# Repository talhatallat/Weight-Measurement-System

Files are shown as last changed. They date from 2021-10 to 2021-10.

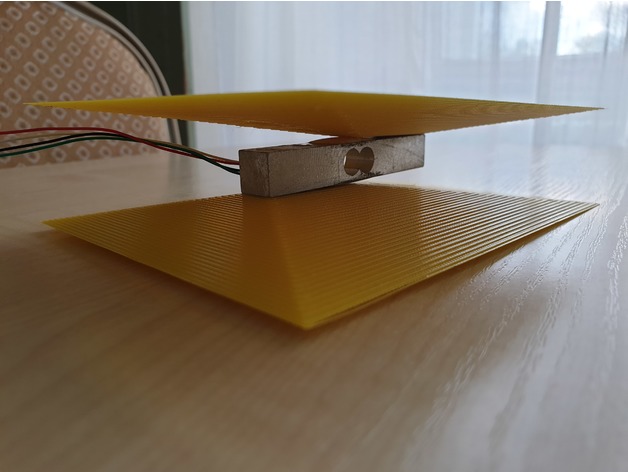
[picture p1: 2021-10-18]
Weight messurment device images/printed.jpg

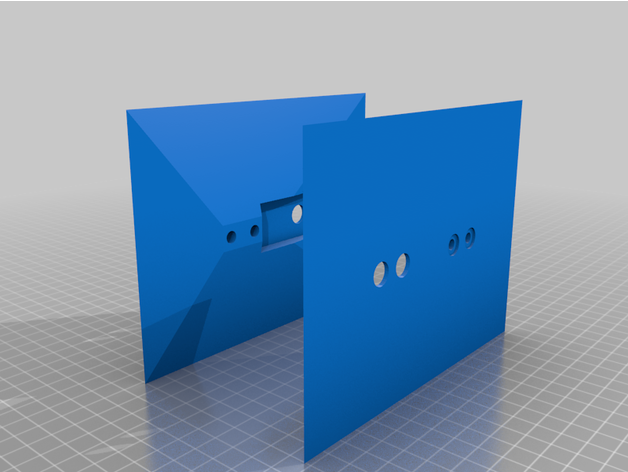
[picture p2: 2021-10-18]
Weight messurment device images/Load-cell_20kg-v3.png

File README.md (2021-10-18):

# Weight Measurement System Using LoadCell <a href="https://dt021a-3.wixsite.com/website/about/" target= "_blank" >View Project</a> 

This project uses Arduino Nano which was programmed to measure the weight accurately when the load is applied to the load cell.

## Load Cell 

A load cell measures the weight using strain gauges. The difference between the length of the load cell at one side of the cell will help in determining the weight that is applied to it. This will change the output impedance.  
The output impedance is integrated into a Wheatstone bridge where the difference of the output impedance determines and controls the output voltage of the circuit.

load-cell-bar-0-5kg-1188-52-B

The load sensor is placed between two 3d printed design plates to measure the load and has spacers between to avoid any extra load or producing any wrong values. 

printed

Load-cell_20kg-v3

*This models were created by Thingiverse user majaczech, and is licensed under cc.*

## Block Diagram



## Project Instructions

<ul>
<li>Apply weight to the load cell</li>
<li>Length of bar will change and that will effect the strain gauge</li>
<li>The change in the strain gauge will vary the resistance</li>
<li>As the resistance of the four strain gauges vary the output of the Wheatstone bridge will vary accordingly</li>
<li>The output from the Wheatstone bridge will be amplified using a differential amplifier</li>
<li>The output of the operational amplifier is inputted into an analogue to digital converter (Arduino Nano) which converts the voltage into digital units (DU)</li>
<li>The digital units are then rescaled to be converted into mass (kg)</li>
</ul>

## Wheatstone Bridge



## Circuit diagram of OP-AMP



## Circuit Calculations & Breakdown

The circuit shown above is a differential operational amplifier to amplify the signal with a gain of 555.5. Where the gain of the op-amp depends on the feedback resistors (Rf/R1) = (1000000/1800) = 555.5.
The input voltages are voltages from the load cell in a Wheatstone bridge configuration (green wire +V) & (White wire -V). The load cell has a minimum output impedance of 900 ohms and a maximum output impedance of 1100 ohms.
This example shows how to implement and apply the load cell using all four strain gauges (R1-R4) where R1 and R3 = R+(change in R) and where R2 and R4 = R-(change in R).
Therefore,
Vobridge=Vs[(change in R)/R]
Voamp=VobridgexGain

Example:
        Vobridge=5(100/1000)=0.5V
        Voamp=(2.744-2.256)x10=4.8V

The Vobridge is theoretical however, the Voamp is calculated that's why there is a 0.2V error

## Rescale

Capture

The A/D values were taken on the Excel sheet for varying load applied to the load cell to find the values for the equation line. Where Y is values read from the load cell. 
X = Y - 22.5 / 0.3495

## Construction



## <a href="https://dt021a-3.wixsite.com/website/about/" target= "_blank" >View Project</a>

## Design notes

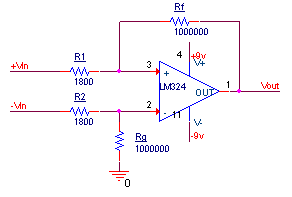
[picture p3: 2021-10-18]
Circuit Designs/Opamp.png

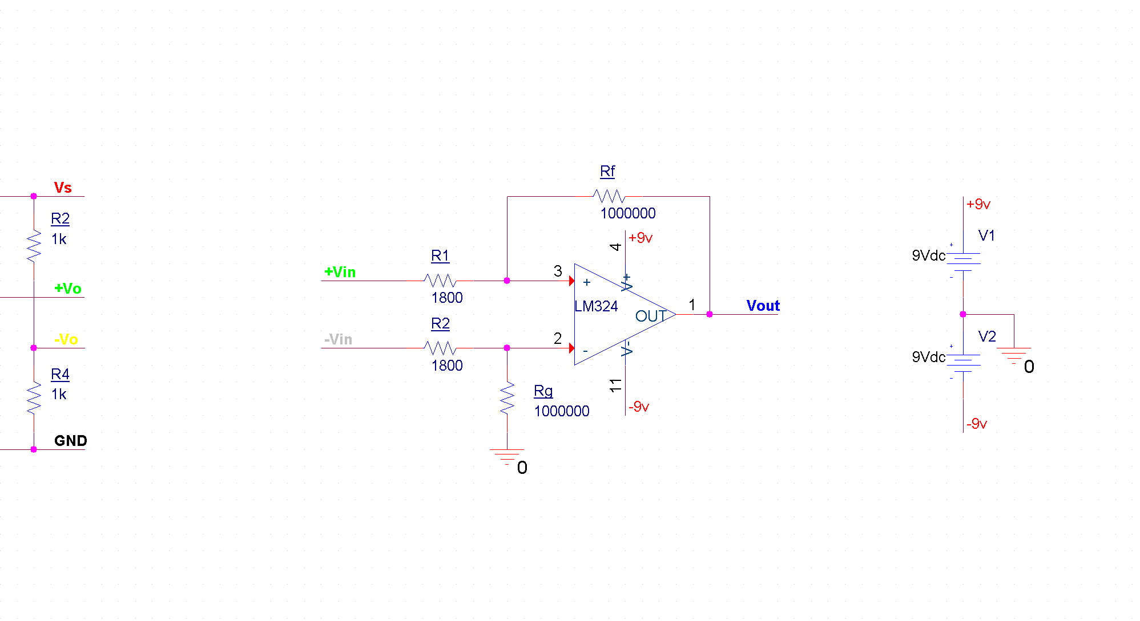
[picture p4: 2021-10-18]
Circuit Designs/LOAD CELL AMPLIFIER.png

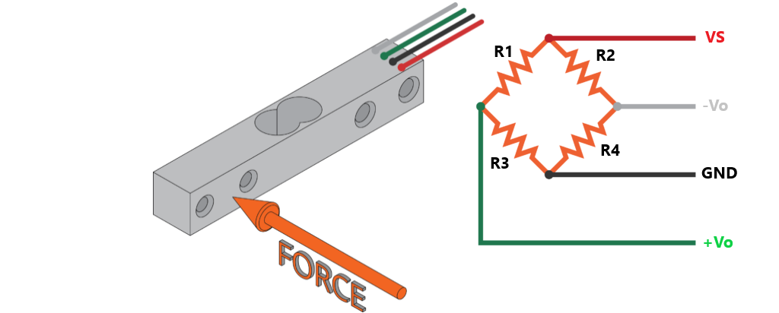
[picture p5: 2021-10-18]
Weight messurment device images/WeatstoneBridge.png

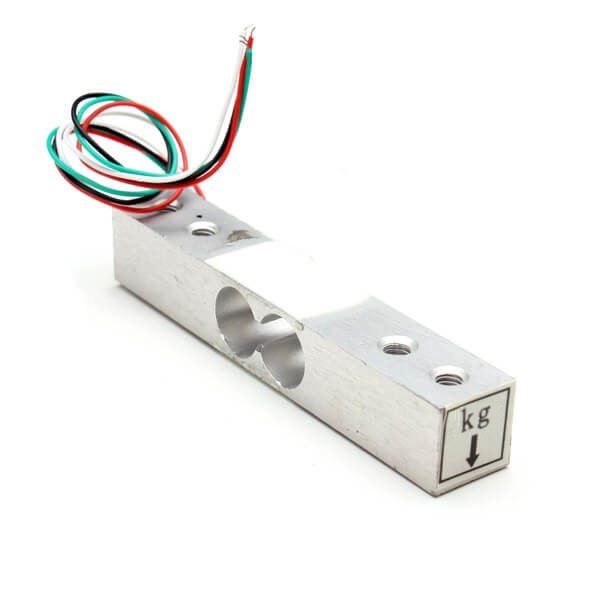
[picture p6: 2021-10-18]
Weight messurment device images/load-cell-bar-0-5kg-1188-52-B.jpg

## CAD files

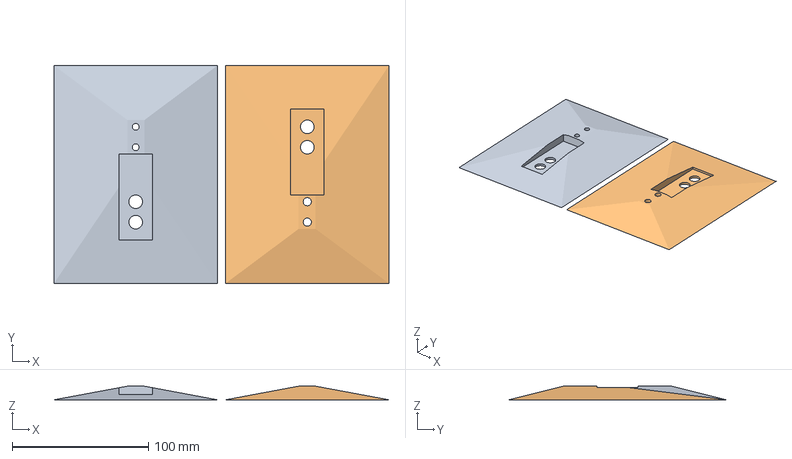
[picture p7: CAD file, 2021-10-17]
3d Printer files/Load-cell_20kg-v3.3mf
246.0 x 160.0 x 10.0 mm
Load-cell 20kg-v8.stl_1
Load-cell 20kg-v8.stl_2

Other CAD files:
3d Printer files/Load-cell_20kg-v2.3mf
3d Printer files/Load-cell_20kg-v2.stl
3d Printer files/Load-cell_20kg-v3.stl

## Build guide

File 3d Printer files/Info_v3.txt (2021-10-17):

V3 improvements: 
- Increased space for sensor
- Iproved holes for screws

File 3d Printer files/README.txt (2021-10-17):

Scale base for load cell by majaczech on Thingiverse: https://www.thingiverse.com/thing:4330707

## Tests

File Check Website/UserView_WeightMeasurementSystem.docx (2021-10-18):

https://dt021a-3.wixsite.com/website/about

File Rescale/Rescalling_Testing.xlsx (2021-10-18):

A Load (g) | M Load (g) | Vout (mv) | A/D
0 | 15 | 0.08 | 16
100 | 47 | 0.23 | 49
200 | 78 | 0.39 | 81
300 | 110 | 0.55 | 113
400 | 144 | 0.7 | 140
500 | 172 | 0.86 | 176
600 | 207 | 1.05 | 212
700 | 238 | 1.19 | 244
800 | 269 | 1.34 | 276
900 | 301 | 1.51 | 308
1000 | 332 | 1.7 | 340
Y = 0.325 x + 15.227
x= y-15.227 / 0.325
A Load (g) | M Load (g) | Vout (mv) | A/D
0 | 2.38 | 0.07 | 15
100 | 97.76 | 0.23 | 48
200 | 196.22 | 0.39 | 79
300 | 294.69 | 0.54 | 111
400 | 390.07 | 0.7 | 142
500 | 485.46 | 0.85 | 174
600 | 586.99 | 1 | 205
700 | 682.38 | 1.15 | 236
800 | 774.69 | 1.3 | 267
900 | 857.76 | 1.43 | 294
1000 | 934.69 | 1.56 | 319
A Load (g) | M Load (g) | Vout (mv) | A/D
0 | -10.2 | 0.07 | 14
100 | 93.9 | 0.23 | 47
200 | 194.74 | 0.38 | 78
300 | 295.59 | 0.54 | 109
400 | 396.43 | 0.68 | 140
500 | 497.28 | 0.84 | 171
600 | 598.13 | 0.99 | 202
700 | 702.23 | 1.14 | 234
800 | 803.07 | 1.3 | 265
900 | 887.65 | 1.42 | 286
1000 | 991.75 | 1.58 | 323
A Load (g) | M Load (g) | Vout (mv) | A/D
0 | 4.74 | 0.07 | 17
100 | 93.9 | 0.23 | 47
200 | 194.74 | 0.38 | 78
300 | 295.59 | 0.54 | 108
400 | 396.43 | 0.68 | 143
500 | 497.28 | 0.84 | 174
600 | 598.13 | 0.99 | 202
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

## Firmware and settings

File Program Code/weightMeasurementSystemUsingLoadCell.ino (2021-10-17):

/*
 Programmer Name: Talha Tallat
 Program Name: Weight Measurement System
 Program Description: Arduino Nano was programmed to measure the weight accurately when the load is applied to the load cell 
 Date: 20-12-2020
*/

float analog3 = A0;

void setup(){
  // put your setup code here, to run once:
  Serial.begin (9600); //bit rate 
}

void loop(){

  float sensorVal = analogRead(analog3); // Read analogue data from input A0 and stored into the "sensorVal" variable 

  float vlotage = sensorVal/204.6; // divding by the digital unit 

  float grams = (sensorVal-22.5) / 0.3495; // Rescaled using line equation 

 Serial.print(" Voltage: ");
 Serial.print(vlotage);

 Serial.print("   A/D value: ");
 Serial.print(sensorVal     );

 Serial.print("   grams: ");
 Serial.print(grams);
 Serial.println("\n---------------------------------------------------");
 
 delay(1000); // delay of 1 sec
}

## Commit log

2021-10-17 STL Files uploaded
    Note: Those STL files were created by majaczech
    [Load-cell_20kg-v2.3mf, Load-cell_20kg-v2.stl, Load-cell_20kg-v3.3mf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]
2021-10-18 Project Circuit designs files uploaded
    [Load cell Amplifier.dsn]
2021-10-18 Demo links file uploaded
    Links are attached in the word document
2021-10-18 Rescale files uploaded
    [Rescalling_Testing.xlsx]
